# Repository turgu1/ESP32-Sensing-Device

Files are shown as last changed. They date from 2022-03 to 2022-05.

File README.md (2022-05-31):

# ESP32 Sensing device V2.0

## Updates

(Updated May 31, 2022)

Received the V2.0 PCBs yesterday. First modifications (Not shown on the schematic):

- Led resistors (R13, R16): 1 kOhms instead of 220 Ohms (the LEDs are way too bright).
- Thermistor 10 kOhms resistor R11 hooked to GPIO25 instead of 3.3V using a wire: To diminish thermistor heath effect on reading values, the GPIO25 is put high only at thermistor read time.

The thermistor is only used when the device is connected to an external source of power: to get an accurate 3.3v source for thermistor read-outs.

To compensate for the lack of linearity of the ESP32 A2D, a lookup table has been generated and used by the software (ESPHome). See the generator here: `software/lut_gener.ino` Pins 34 and 25 must be connected before using the generator (without the GPIO34 resistor). Must be used for each ESP32 instance (will be different for each ESP32 chip). An example of the generated table can be found here: `software/.freezer_adc_lut.h`.

An ESPHome example of use to sense a Freezer is supplied in `software/freezer.yaml`.

(Updated May 19, 2022)

The new version is ready for production. Here are the modifications from version 1.0:

- Sensors using GPIO 15 (Generic sensor), 25 (thermistor) and 27 (light sensor) migrated to GPIO 32, 34 and 35 respectively
- Added I2C interface
- Added program-controlled led
- All parts are aligned in the same direction onboard, to simplify hand soldering
- The board is 0.6mm larger

(Updated May 18, 2022)

The thermistor and photo-resistor sensors are working well. As they use GPIO 25 and 27 A2D capability (ADC2), the WiFi interface cannot be enabled at the same time the sensors are being read: the ADC2 electronics is shared with the onboard  WiFi capability. An updated version of the device is being prepared to use ADC1 GPIOs instead. (This has been corrected in version 2.0)

(Updated May 17, 2022)

All the trials are positive so far. For R1, instead of 10K, I'm using 2.7M ohms.
Remains the thermistor and photo-resistor sensors to try.

(Updated March 29, 2022)

Initial release.

## Introduction

This is a small footprint ESP32-based sensing device, with the following characteristics:

- 30x28 mm circuit board (30x40 mm with ESP32 antenna)
- Two power modes:
    - Battery (AAx2) (through external battery case)
    - External 5 Volts power support (through power-only Micro USB-B port)
- Battery level monitoring circuit
- Three Sensing ports:
    - Multi-Purpose (configurable through Resistor and Capacitor parts)
    - Thermistor (https://learn.adafruit.com/thermistor/using-a-thermistor)
    - Photoresistor (https://learn.adafruit.com/photocells/using-a-photocell)
- I2C Interface port
- External FTDI port (through a 3-pins [GND, RxD, TxD] port) (https://learn.adafruit.com/ftdi-friend)
- RST / PGM buttons
- Power LED (for external power only)
- Programmable LED
- Designed with KiCAD V6.0.5 (https://www.kicad.org)
- Public Domain

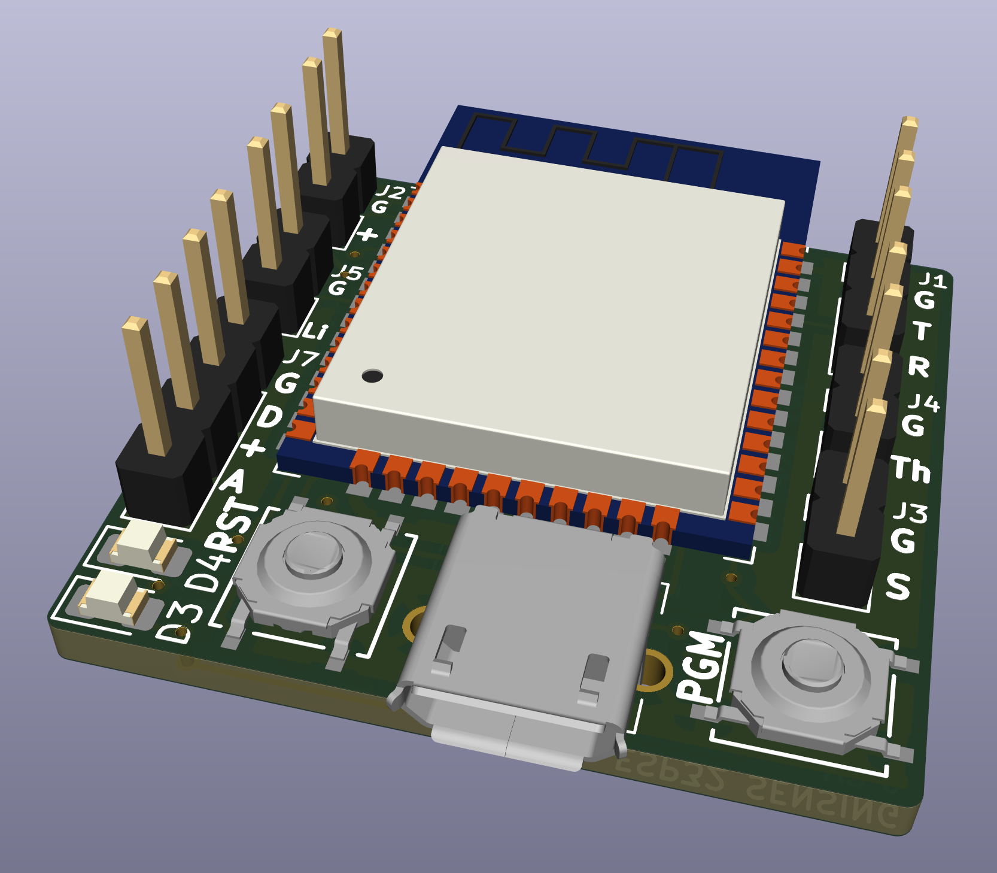
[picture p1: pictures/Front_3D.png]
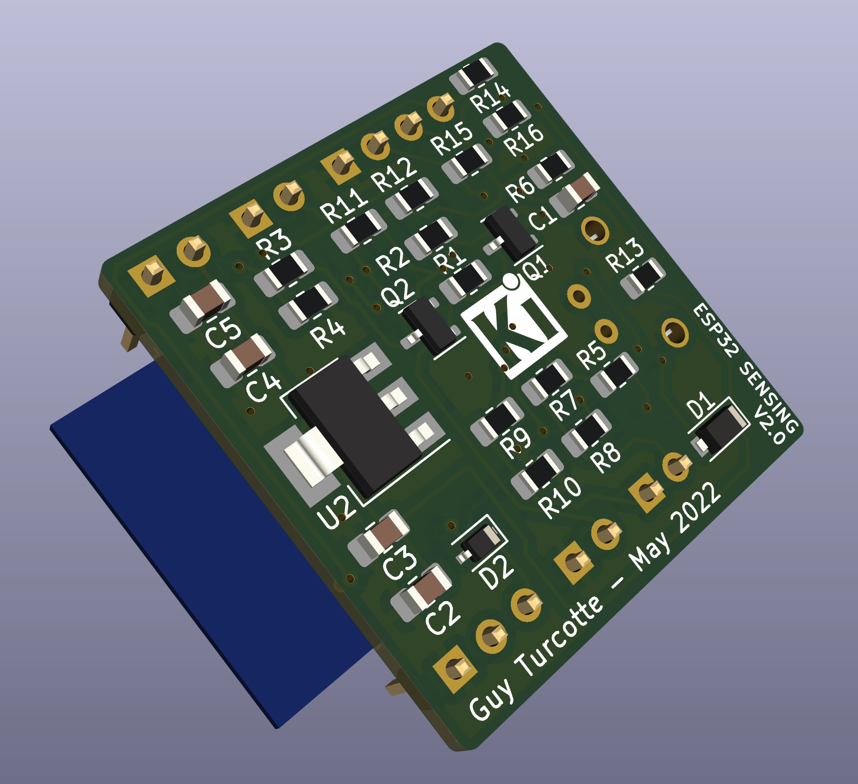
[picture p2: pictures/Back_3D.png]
&nbsp;&nbsp;&nbsp;&nbsp;

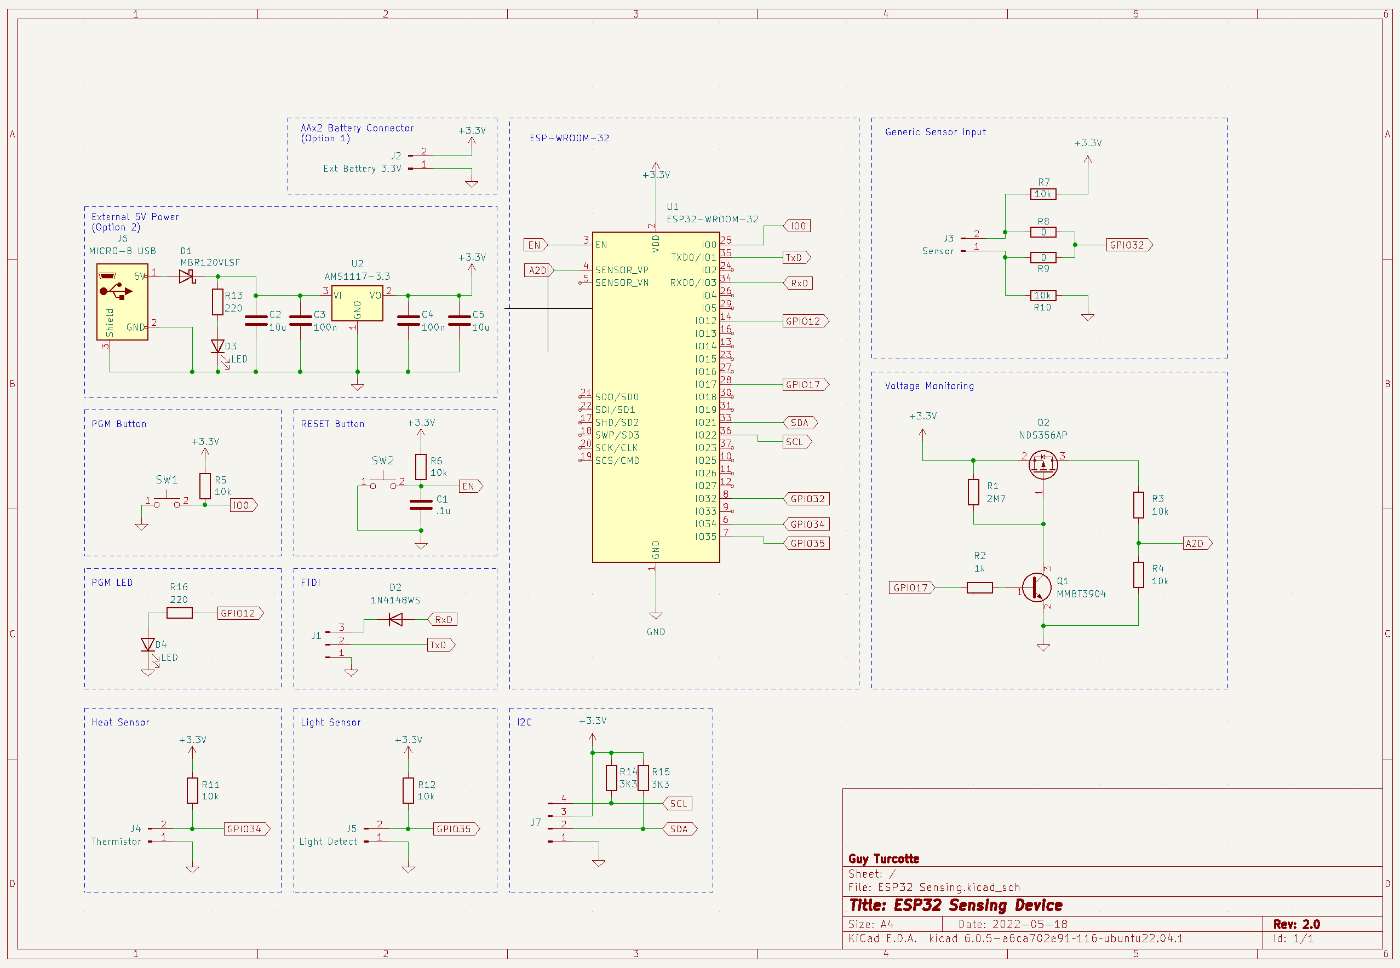
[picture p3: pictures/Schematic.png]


The choice of components is related to their availability in my inventory. 

## Design Description

Looking at the schematic, you will find here the information related to each subsection present on the device. Some subsections are required, and others are optional depending on your needs.

The electronic component identifiers required for each subsection are listed inside square brackets.

### Required Subsections

- **ESP-WROOM-32** [**U1**] - This is the processor in use on the device.
- **RESET Button** [**SW2**, **R6**, **C1**] - Required to maintain the processor working and do a reset when it is required to take back the control for programming or when the device is not behaving properly.
- **PGM Button** [**SW1**, **R5**] - For programming the processor, the PGM Button must be pressed as the reset button is also pressed, and then released *after* releasing the reset button, such that the processor will be put in program loading. The FTDI interface must be connected to the computer to transmit the new program.
- **FTDI** [**D2**, **J1**] - This is the connection to an external FTDI device that allows for communication between the ESP32 processor and a development PC for program loading and debugging output. Connector's pins are labeled **G** (Ground), **R** (RxD), and **T** (TxD) relative to the ESP32 pinout: The External FTDI GND pin must be connected to **G**, the FTDI RxD pin must be connected to **T**, and the FTDI TxD pin must be connected to **R**. Power must be supplied to the board through AA batteries or an external power supply.

### Optional Subsections

- **AAx2 Battery Connector** [**J2**] - If power is to be supplied with AA batteries, the connector is required. The battery holder wires can also be directly soldered in the through-holes. Please respect the polarity (a '+' sign is present on the board to indicate the positive wire location). **Do not connect any battery if you intend to use an external power supply.**
- **External 5V Power**, [**U2**, **J6**, **D1**, **D3**, **R13**, **C2**, **C3**, **C4**, **C5**] - This is a linear 3.3V regulator circuit, only required when a DC 5 Volts power supply is used. It is expected that the power supply is using a male micro USB-B connector. **Do not implement this subsection if you intend to use batteries.**
- **Voltage Monitoring** [**Q1**, **Q2**, **R1**, **R2**, **R3**, **R4**] - This circuit will allow for reading the 3.3 V power voltage for the device through ADC1_0 internal to the ESP32. If AA batteries are used, it will allow monitoring the battery level to replace them when required. The MOSFET transistor [**Q2**] insure that the circuit will not take a load on the batteries. Must be enabled through [**Q1**] using GPIO17.
- **Generic Sensor Input** [**J3**, **R7**, **R8**, **R9**, **R10**] - This is a port to retrieve some sensor information. The four resistors must be adjusted to consider the kind of sensing to be done (pull-up, pull-down, etc.). Some resistor locations can be used for capacitors if required (e.g. adding an RC circuit). This sensor is connected to GPIO32 (ADC1_4) of the ESP32. The J3 pins are labeled 1: G (Gnd), 2: S (Signal).
- **Heat Sensor** [**J4**, **R11**] - Allow for reading the level of Heat using an external thermistor through an A2D of the processor (ADC1). This sensor is connected to GPIO34 (ADC1_6) of the ESP32. Can be used with another kind of sensor as appropriate. The J4 pins are labeled 1: G (Gnd), 2: Th (Signal).
- **Light Sensor** [**J5**, **R12**] - Allow for reading the level of Heat using an external photoresistor through an A2D of the processor (ADC1). This sensor is connected to GPIO35 (ADC1_7) of the ESP32. Can be used with another kind of sensor as appropriate. The J5 pins are labeled 1: G (Gnd), 2: Li (Signal).
- **I2C Interface** [**J7**, **R14**, **R15**] - Used to connect to external I2C devices (displays, sensors, etc). Connected to the ESP32 through GPIO21 (SDA) and GPIO22 (SCL). The J7 connector offers 3.3v and GND pins. Resistors may have to be adjusted depending on the load. The J7 Pins are labeled 1: G (ground), 2: D (SDA), 3: + (3.3v), 4: C (SCL)
- **Program Controlled LED** [**D4**, **R16**] - Could be useful for debugging purpose. Not a good idea to use it on battery-powered devices. Connected to ESP32 GPIO12. Important: Must be programmed as an output GPIO.



### Some potential issues

- The thermistor and photoresistive interfaces are exploratory. The known lack of linearity of the ESP32 A2D may have an impact on the quality of the retrieved data. See [here](https://www.e-tinkers.com/2019/10/using-a-thermistor-with-arduino-and-unexpected-esp32-adc-non-linearity/), and [here](https://rntlab.com/question/analogread-for-ntc-thermistor/) for further information.

- The Micro USB-B connector is a specific part with only 2 through-hole pins (GND and 5V). See the BOM below for purchase locations. On Amazon, there are 100, 30, and 10 pieces bundles available. A more conventional 5-pins connector may be adapted (physical tweak or modification to the board design).

- The Power LED is for use only with the external power supply and is hooked on the 5v side of the linear regulator. It could have been hooked to the 3.3v side, closer to the ESP32.

- The linear 3.3v regulator capacitors may have to be different than the one selected. In particular, on the output side, to get a better transient response, a 22uF tantalum may replace the one indicated (per the AMS1117 spec sheet).

- Using batteries to power the device: depending on the processor speed and the networking requirements at startup (WiFi, BT, BLE), the AA batteries may not be able to supply the required startup current (100 to 500 mA). Many options are possible: use larger batteries, lithium instead of alkaline, and add some capacitors (tantalum or other) at C4/C5 locations.

## Bill of Material (BOM)

| Reference(s) | Value | Footprint | Where to find |
|:---:|:-----:|:---:|:---|
| C1 | .1uF  | 0805 | |
| C2, C5 | 10uF  | 0805 | |
| C3, C4 | 100nF | 0805 | |
| D1 | MBR120VLSF or equivalent | SOD-123 | [e-Radionica](https://e-radionica.com/en/schottky-diode-mbr120vlsft3g-sod123.html), [Digikey](https://www.digikey.com/en/products/detail/on-semiconductor/MBR120VLSFT3G/1477157), [Mouser](https://www.mouser.com/ProductDetail/onsemi/MBR120VLSFT3G?qs=3JMERSakebrD2yr9jFliaA%3D%3D) |
| D2 | 1N4148WS | SOD-323 | [Digikey](https://www.digikey.com/en/products/detail/on-semiconductor/1N4148WS/1873805), [Mouser](https://www.mouser.ca/ProductDetail/onsemi-Fairchild/1N4148WS?qs=2%2FYqgE%252BHg%252BKBrKZlAsMLhw%3D%3D) |
| D3, D4 | LED | 0805 | |
| J1 | Connector 1x3 | Pin Header 2.54mm | |
| J2, J3, J4, J5 | Connector 1x2 | Pin Header 2.54mm | |
| J6 | Micro-B USB | | [AliExpress](https://fr.aliexpress.com/item/32886396127.html?gatewayAdapt=glo2fra), [Amazon](https://www.amazon.com/uxcell-100PCS-Connector-Replacement-Adapter/dp/B07R1HG29D/ref=psdc_172544_t1_B07R1HRM1T) |
| J7 | Connector 1x4 | Pin Header 2.54mm | |
| Q1 | MMBT3904 | SOT-23 | |
| Q2 | NDS356AP or IRLML5103TRPBF or equivalent | SOT-23 | |
| R1, R3 to R7, R10 to R12 | 10k ohms | 0805 | |
| R2 | 1k ohms | 0805 | |
| R8, R9 | 0 ohms | 0805 | |
| R13, R16 | 220 ohms | 0805 | |
| R14, R15 | 3.3k ohms | 0805 | |
| SW1, SW2 | PTS526_SK15_SMTR2_LFS | SMTR2 | [Mouser](https://www.mouser.com/ProductDetail/CK/PTS526-SK15-SMTR2-LFS?qs=UXgszm6BlbF5Ezp94JAQtw%3D%3D), [Digikey](https://www.digikey.com/en/products/detail/c-k/PTS526-SK15-SMTR2-LFS/10056626), [e-Radionica](https://e-radionica.com/en/smd-pushbutton.html) |
| U1 | ESP-WROOM-32 | | [e-Radionica](https://e-radionica.com/en/esp32-wroom-32d-wifi-module.html) |
| U2 | AMS1117-3.3 | SOT-223-3 | |

## Copyright (c) 2022 Guy Turcotte

Permission is hereby granted, free of charge, to any person obtaining a copy of this project and associated documentation files (the "Project Content"), to deal in the Project without restriction, including without limitation the rights to use, copy, modify, merge, publish, distribute, sublicense, and/or sell copies of the Project Content, and to permit persons to whom the Project Content is furnished to do so, subject to the following conditions:

The above copyright notice and this permission notice shall be included in all copies or substantial portions of the Project Content.

THE PROJECT CONTENT IS PROVIDED "AS IS", WITHOUT WARRANTY OF ANY KIND, EXPRESS OR IMPLIED, INCLUDING BUT NOT LIMITED TO THE WARRANTIES OF MERCHANTABILITY, FITNESS FOR A PARTICULAR PURPOSE, AND NON-INFRINGEMENT. IN NO EVENT SHALL THE AUTHORS OR COPYRIGHT HOLDERS BE LIABLE FOR ANY CLAIM, DAMAGES, OR OTHER LIABILITY, WHETHER IN AN ACTION OF CONTRACT, TORT OR OTHERWISE, ARISING FROM, OUT OF OR IN CONNECTION WITH THE PROJECT CONTENT OR THE USE OR OTHER DEALINGS IN THE PROJECT CONTENT.

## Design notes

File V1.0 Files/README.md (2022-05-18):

# ESP32 Sensing device V1.0

(Update May 18, 2022)

The thermistor and photo-resistor sensors are working well. As they use GPIO 25 and 27 A2D capability (ADC2), the WiFi interface cannot be enabled at the same time the sensors are being read: the ADC2 electronics is shared with the onboard  WiFi capability. An updated version of the device is being prepared to use ADC1 GPIOs instead.

(Update May 17, 2022)

All the trials are positive so far. For R1, instead of 10K, I'm using 2.7M ohms.
Remains the thermistor and photo-resistor sensors to try.

(Updated March 29, 2022)

This is a small footprint ESP32-based sensing device, with the following characteristics:

- 30x28 mm circuit board (30x40 mm with ESP32 antenna)
- Two power modes:
    - Battery (AAx2) (through external battery case)
    - External 5 Volts power support (through power-only Micro USB-B port)
- Battery level monitoring circuit
- Three Sensing ports:
    - Multi-Purpose (configurable through Resistor and Capacitor parts)
    - Thermistor (https://learn.adafruit.com/thermistor/using-a-thermistor)
    - Photoresistor (https://learn.adafruit.com/photocells/using-a-photocell)
- External FTDI port (through a 3-pins [GND, RxD, TxD] port) (https://learn.adafruit.com/ftdi-friend)
- RST / PGM buttons
- Power LED (for external power only)
- Designed with KiCAD V6.0.4 (https://www.kicad.org)
- Public Domain

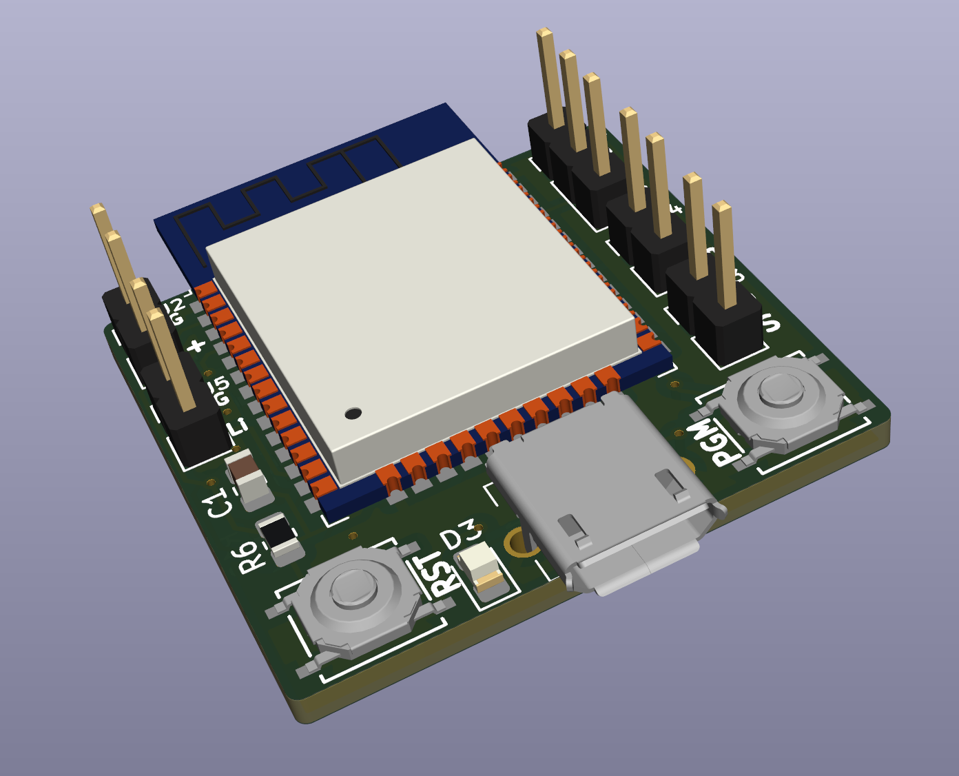
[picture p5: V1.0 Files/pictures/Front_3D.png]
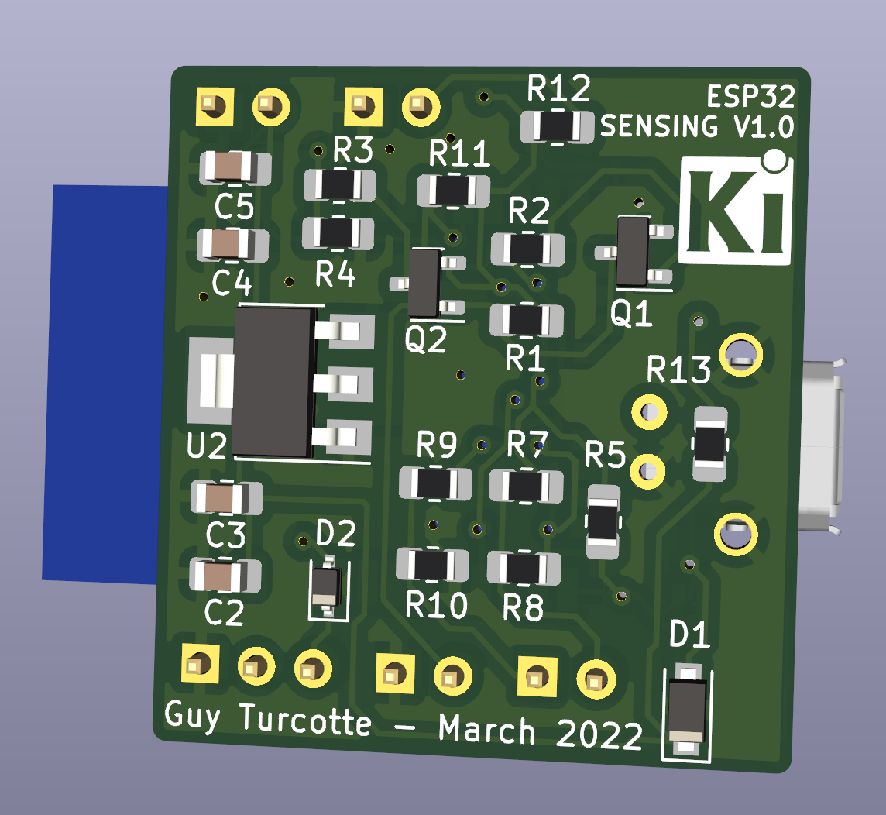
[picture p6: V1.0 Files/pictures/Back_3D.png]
&nbsp;&nbsp;&nbsp;&nbsp;

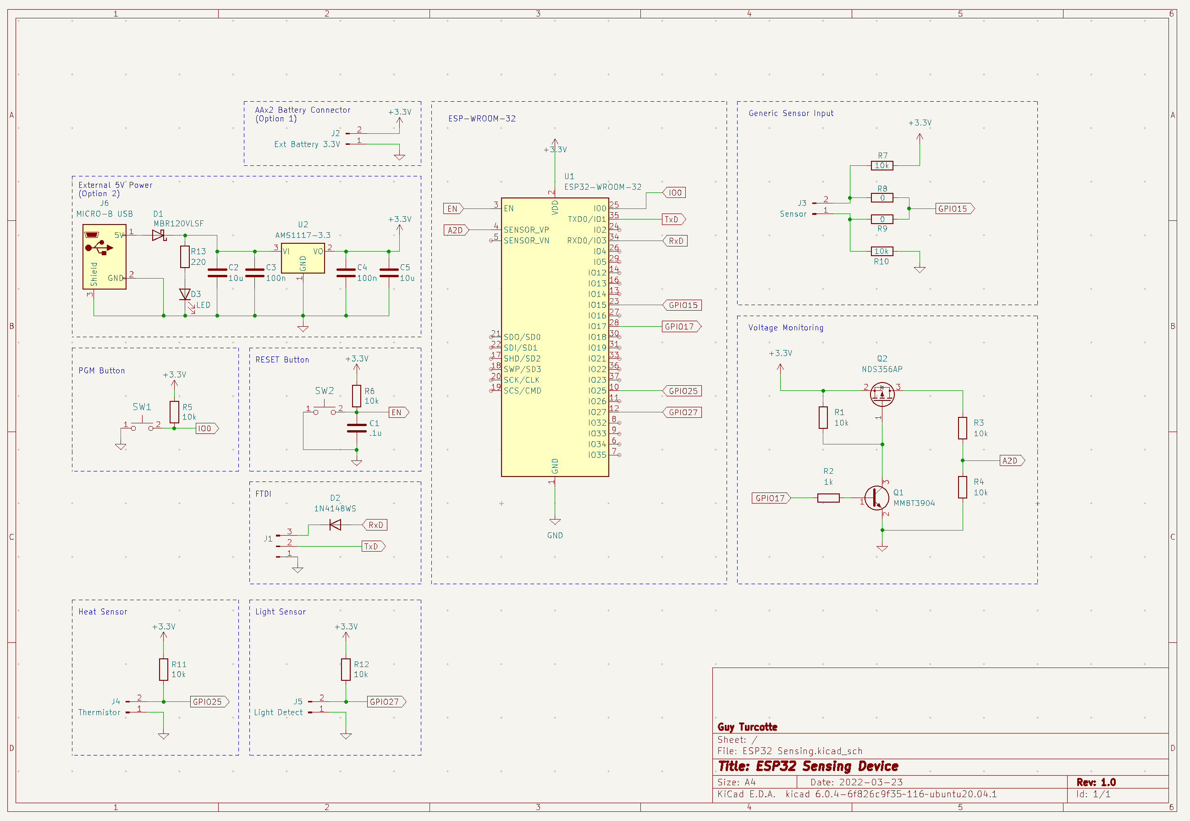
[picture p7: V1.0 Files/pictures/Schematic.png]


The choice of components is related to their availability in my inventory. 

## Design Description

Looking at the schematic, you will find here the information related to each subsection present on the device. Some subsections are required, others are optional depending on your needs.

The electronic component identifiers required for each subsection are listed inside square brackets.

### Required Subsections

- **ESP-WROOM-32** [**U1**] - This is the processor in use on the device.
- **RESET Button** [**SW2**, **R6**, **C1**] - Required to maintain the processor working and do a reset when it is required to take back the control for programming or when the device is not behaving properly.
- **PGM Button** [**SW1**, **R5**] - For programming the processor, the PGM Button must be pressed as the reset button is also pressed such that the processor will be put in program loading. The FTDI interface must be connected to the computer to transmit the new program.
- **FTDI** [**D2**, **J1**] - This is the connection to an external FTDI device that allows for communication between the ESP32 processor and a development PC for program loading and debugging output. Connector's pins are labeled **G** (Ground), **R** (RxD), and **T** (TxD) relative to the ESP32 pinout: The External FTDI GND pin must be connected to **G**, the FTDI RxD pin must be connected to **T**, and the FTDI TxD pin must be connected to **R**. Power must be supplied to the board through AA batteries or external power supply.

### Optional Subsections

- **AAx2 Battery Connector** [**J2**] - If power is to be supplied with AA batteries, the connector is required. The batteries holder wires can also be directly soldered in the through-holes. Please respect the polarity (a '+' sign is present on the board to indicate the positive wire location). **Do not connect any battery if you intend to use an external power supply.**
- **External 5V Power**, [**U2**, **J6**, **D1**, **D3**, **R13**, **C2**, **C3**, **C4**, **C5**] - This is a linear 3.3V regulator circuit, only required when a DC 5 Volts power supply is used. It is expected that the power supply is using a male micro USB-B connector. **Do not implement this subsection if you intend to use batteries.**
- **Voltage Monitoring** [**Q1**, **Q2**, **R1**, **R2**, **R3**, **R4**] - This circuit will allow for reading the 3.3 V power voltage for the device through ADC1_0 internal to the ESP32. If AA batteries are used, it will allow monitoring the battery level to replace them when required. The MOSFET transistor [**Q2**] insure that the circuit will not take a load on the batteries. Must be enabled through [**Q1**] using GPIO17.
- **Generic Sensor Input** [**J3**, **R7**, **R8**, **R9**, **R10**] - This is a port to retrieve some sensor information. The four resistors must be adjusted to consider the kind of sensing to be done (pull-up, pull-down, etc.). Some resistors locations can be used for capacitors if required (e.g. adding an RC circuit). This sensor is connected to GPIO15 (ADC2_3) of the ESP32.
- **Heat Sensor** [**J4**, **R11**] - Allow for reading the level of Heat using an external thermistor through an A2D of the processor (ADC2). This sensor is connected to GPIO25 (ADC2_8) of the ESP32. Can be used with another kind of sensor as appropriate. As the ADC2 circuitry is also used by the WiFi interface, the WiFi interface cannot be enabled at the same time the sensor is being read.
- **Light Sensor** [**J5**, **R12**] - Allow for reading the level of Heat using an external photoresistor through an A2D of the processor (ADC2). This sensor is connected to GPIO27 (ADC2_7) of the ESP32. Can be used with another kind of sensor as appropriate. As the ADC2 circuitry is also used by the WiFi interface, the WiFi interface cannot be enabled at the same time the sensor is being read.



### Some potential issues

- The thermistor and photoresistive interfaces are exploratory. The known lack of linearity of the ESP32 A2D may have an impact on the quality of the retrieved data. See [here](https://www.e-tinkers.com/2019/10/using-a-thermistor-with-arduino-and-unexpected-esp32-adc-non-linearity/), and [here](https://rntlab.com/question/analogread-for-ntc-thermistor/) for further information.

- The Micro USB-B connector is a specific part with only 2 through-hole pins (GND and 5V). See the BOM below for purchase locations. On Amazon, there are 100, 30, and 10 pieces bundles available. A more conventional 5-pins connector may be adapted (physical tweak or modification to the board design).

- The LED is for use only with the external power supply and is hooked on the 5v side of the linear regulator. It could have been hooked to the 3.3v side, closer to the ESP32.

- The linear 3.3v regulator capacitors may have to be different than the one selected. In particular, on the output side, to get a better transient response, a 22uF tantalum may replace the one indicated (per the AMS1117 spec sheet).

- Using batteries to power the device: depending on the processor speed and the networking requirements at startup (WiFi, BT, BLE), the AA batteries may not be able to supply the required startup current (100 to 500 mA). Many options are possible: use larger batteries, lithium instead of alkaline, add some capacitors (tantalum or other) at C4/C5 locations.

## Bill of Material (BOM)

| Reference(s) | Value | Footprint | Where to find |
|:---:|:-----:|:---:|:---|
| C1 | .1uF  | 0805 | |
| C2, C5 | 10uF  | 0805 | |
| C3, C4 | 100nF | 0805 | |
| D1 | MBR120VLSF or equivalent | SOD-123 | [e-Radionica](https://e-radionica.com/en/schottky-diode-mbr120vlsft3g-sod123.html), [Digikey](https://www.digikey.com/en/products/detail/on-semiconductor/MBR120VLSFT3G/1477157), [Mouser](https://www.mouser.com/ProductDetail/onsemi/MBR120VLSFT3G?qs=3JMERSakebrD2yr9jFliaA%3D%3D) |
| D2 | 1N4148WS | SOD-323 | [Digikey](https://www.digikey.com/en/products/detail/on-semiconductor/1N4148WS/1873805), [Mouser](https://www.mouser.ca/ProductDetail/onsemi-Fairchild/1N4148WS?qs=2%2FYqgE%252BHg%252BKBrKZlAsMLhw%3D%3D) |
| D3 | LED | 0805 | |
| J1 | Connector 1x3 | Pin Header 2.54mm | |
| J2, J3, J4, J5 | Connector 1x2 | Pin Header 2.54mm | |
| J6 | Micro-B USB | | [AliExpress](https://fr.aliexpress.com/item/32886396127.html?gatewayAdapt=glo2fra), [Amazon](https://www.amazon.com/uxcell-100PCS-Connector-Replacement-Adapter/dp/B07R1HG29D/ref=psdc_172544_t1_B07R1HRM1T) |
| Q1 | MMBT3904 | SOT-23 | |
| Q2 | NDS356AP or IRLML5103TRPBF or equivalent | SOT-23 | |
| R1, R3 to R7, R10 to R12 | 10k ohms | 0805 | |
| R2 | 1k ohms | 0805 | |
| R8, R9 | 0 ohms | 0805 | |
| R13 | 220 ohms | 0805 | |
| SW1, SW2 | PTS526_SK15_SMTR2_LFS | SMTR2 | [Mouser](https://www.mouser.com/ProductDetail/CK/PTS526-SK15-SMTR2-LFS?qs=UXgszm6BlbF5Ezp94JAQtw%3D%3D), [Digikey](https://www.digikey.com/en/products/detail/c-k/PTS526-SK15-SMTR2-LFS/10056626), [e-Radionica](https://e-radionica.com/en/smd-pushbutton.html) |
| U1 | ESP-WROOM-32 | | [e-Radionica](https://e-radionica.com/en/esp32-wroom-32d-wifi-module.html) |
| U2 | AMS1117-3.3 | SOT-223-3 | |

## Copyright (c) 2022 Guy Turcotte

Permission is hereby granted, free of charge, to any person obtaining a copy of this project and associated documentation files (the "Project Content"), to deal in the Project without restriction, including without limitation the rights to use, copy, modify, merge, publish, distribute, sublicense, and/or sell copies of the Project Content, and to permit persons to whom the Project Content is furnished to do so, subject to the following conditions:

The above copyright notice and this permission notice shall be included in all copies or substantial portions of the Project Content.

THE PROJECT CONTENT IS PROVIDED "AS IS", WITHOUT WARRANTY OF ANY KIND, EXPRESS OR IMPLIED, INCLUDING BUT NOT LIMITED TO THE WARRANTIES OF MERCHANTABILITY, FITNESS FOR A PARTICULAR PURPOSE, AND NON-INFRINGEMENT. IN NO EVENT SHALL THE AUTHORS OR COPYRIGHT HOLDERS BE LIABLE FOR ANY CLAIM, DAMAGES, OR OTHER LIABILITY, WHETHER IN AN ACTION OF CONTRACT, TORT OR OTHERWISE, ARISING FROM, OUT OF OR IN CONNECTION WITH THE PROJECT CONTENT OR THE USE OR OTHER DEALINGS IN THE PROJECT CONTENT.

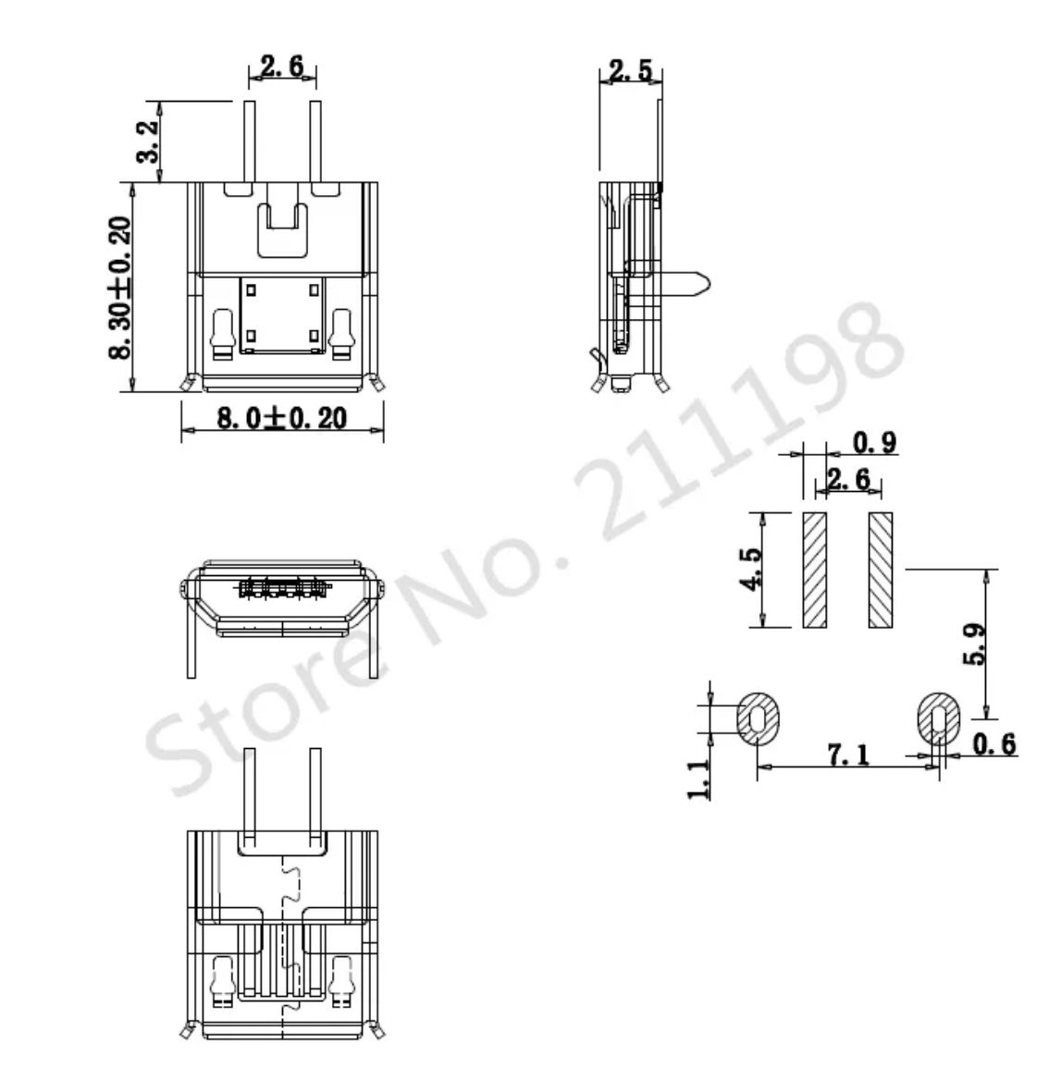
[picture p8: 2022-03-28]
V1.0 Files/pictures/Micro USB-B 2-pins dimensions.png

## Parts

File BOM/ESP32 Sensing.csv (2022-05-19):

Id | Designator | Package | Quantity | Designation | Supplier and ref
1 | J5 | PinHeader_1x02_P2.54mm_Vertical | 1 | Light Detect
2 | J3 | PinHeader_1x02_P2.54mm_Vertical | 1 | Sensor
3 | J7 | PinHeader_1x04_P2.54mm_Vertical | 1 | Conn_01x04_Male
4 | D4,D3 | LED_0805_2012Metric_Pad1.15x1.40mm_HandSolder | 2 | LED
5 | SW1 | PTS526_SK15_SMTR2_LFS | 1 | PTS526_SK15_SMTR2_LFS
6 | J1 | PinHeader_1x03_P2.54mm_Vertical | 1 | ~
7 | J2 | PinHeader_1x02_P2.54mm_Vertical | 1 | Ext Battery 3.3V
8 | U1 | ESP32-WROOM-32 | 1 | ESP32-WROOM-32
9 | J4 | PinHeader_1x02_P2.54mm_Vertical | 1 | Thermistor
10 | SW2 | PTS526_SK15_SMTR2_LFS | 1 | ~
11 | J6 | MICRO-B_USB_POWER | 1 | MICRO-B USB
12 | R13,R16 | R_0805_2012Metric_Pad1.20x1.40mm_HandSolder | 2 | 220
13 | R7,R4,R3,R10,R5,R12,R6,R11 | R_0805_2012Metric_Pad1.20x1.40mm_HandSolder | 8 | 10k
14 | R15,R14 | R_0805_2012Metric_Pad1.20x1.40mm_HandSolder | 2 | 3K3
15 | C4,C3 | C_0805_2012Metric_Pad1.18x1.45mm_HandSolder | 2 | 100n
16 | Q1 | SOT-23 | 1 | MMBT3904
17 | R9,R8 | R_0805_2012Metric_Pad1.20x1.40mm_HandSolder | 2 | 0
18 | D1 | D_SOD-123F | 1 | MBR120VLSF
19 | R2 | R_0805_2012Metric_Pad1.20x1.40mm_HandSolder | 1 | 1k
20 | D2 | D_SOD-323 | 1 | 1N4148WS
21 | R1 | R_0805_2012Metric_Pad1.20x1.40mm_HandSolder | 1 | 2M7
22 | U2 | SOT-223-3_TabPin2 | 1 | AMS1117-3.3
23 | C2,C5 | C_0805_2012Metric_Pad1.18x1.45mm_HandSolder | 2 | 10u
24 | Q2 | SOT-23 | 1 | NDS356AP
25 | C1 | C_0805_2012Metric_Pad1.18x1.45mm_HandSolder | 1 | .1u

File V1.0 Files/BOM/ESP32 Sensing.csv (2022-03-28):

Source: | /home/turgu1/Dev/KiCad/ESP32 Sensing/KiCAD/ESP32 Sensing.kicad_sch
Date: | Mon 28 Mar 2022 03:08:43 PM
Tool: | Eeschema 6.0.4-6f826c9f35~116~ubuntu20.04.1
Generator: | /usr/share/kicad/plugins/bom_csv_grouped_by_value.py
Component Count: | 33
Individual Components:
Item | Qty | Reference(s) | Value | LibPart | Footprint | Datasheet
 |  | C1 | .1u | Device:C | Capacitor_SMD:C_0805_2012Metric_Pad1.18x1.45mm_HandSolder | ~
 |  | C2 | 10u | Device:C | Capacitor_SMD:C_0805_2012Metric_Pad1.18x1.45mm_HandSolder | ~
 |  | C3 | 100n | Device:C | Capacitor_SMD:C_0805_2012Metric_Pad1.18x1.45mm_HandSolder | ~
 |  | C4 | 100n | Device:C | Capacitor_SMD:C_0805_2012Metric_Pad1.18x1.45mm_HandSolder | ~
 |  | C5 | 10u | Device:C | Capacitor_SMD:C_0805_2012Metric_Pad1.18x1.45mm_HandSolder | ~
 |  | D1 | MBR120VLSF | Diode:MBR1020VL | Diode_SMD:D_SOD-123F | https://www.onsemi.com/pub/Collateral/MBR1020VL-D.PDF
 |  | D2 | 1N4148WS | Diode:1N4148WS | Diode_SMD:D_SOD-323 | https://www.vishay.com/docs/85751/1n4148ws.pdf
 |  | D3 | LED | Device:LED | LED_SMD:LED_0805_2012Metric_Pad1.15x1.40mm_HandSolder | ~
 |  | J1 | ~ | Connector:Conn_01x03_Male | Connector_PinHeader_2.54mm:PinHeader_1x03_P2.54mm_Vertical | ~
 |  | J2 | Ext Battery 3.3V | Connector:Conn_01x02_Male | Connector_PinHeader_2.54mm:PinHeader_1x02_P2.54mm_Vertical | ~
 |  | J3 | Sensor | Connector:Conn_01x02_Male | Connector_PinHeader_2.54mm:PinHeader_1x02_P2.54mm_Vertical | ~
 |  | J4 | Thermistor | Connector:Conn_01x02_Male | Connector_PinHeader_2.54mm:PinHeader_1x02_P2.54mm_Vertical | ~
 |  | J5 | Light Detect | Connector:Conn_01x02_Male | Connector_PinHeader_2.54mm:PinHeader_1x02_P2.54mm_Vertical | ~
 |  | J6 | MICRO-B USB | ESP32 Sensing:MICRO-B_USB_POWER | ESP32 Sensing:MICRO-B_USB_POWER
 |  | Q1 | MMBT3904 | Transistor_BJT:MMBT3904 | Package_TO_SOT_SMD:SOT-23 | https://www.onsemi.com/pub/Collateral/2N3903-D.PDF
 |  | Q2 | NDS356AP | ESP32 Sensing:NDS356AP | Package_TO_SOT_SMD:SOT-23 | https://rocelec.widen.net/view/pdf/qv8gjztlsc/ONSM-S-A0003585169-1.pdf?t.download=true&u=5oefqw
 |  | R1 | 10k | Device:R | Resistor_SMD:R_0805_2012Metric_Pad1.20x1.40mm_HandSolder | ~
 |  | R2 | 1k | Device:R | Resistor_SMD:R_0805_2012Metric_Pad1.20x1.40mm_HandSolder | ~
 |  | R3 | 10k | Device:R | Resistor_SMD:R_0805_2012Metric_Pad1.20x1.40mm_HandSolder | ~
 |  | R4 | 10k | Device:R | Resistor_SMD:R_0805_2012Metric_Pad1.20x1.40mm_HandSolder | ~
 |  | R5 | 10k | Device:R | Resistor_SMD:R_0805_2012Metric_Pad1.20x1.40mm_HandSolder | ~
 |  | R6 | 10k | Device:R | Resistor_SMD:R_0805_2012Metric_Pad1.20x1.40mm_HandSolder | ~
 |  | R7 | 10k | Device:R | Resistor_SMD:R_0805_2012Metric_Pad1.20x1.40mm_HandSolder | ~
 |  | R8 | 0 | Device:R | Resistor_SMD:R_0805_2012Metric_Pad1.20x1.40mm_HandSolder | ~
 |  | R9 | 0 | Device:R | Resistor_SMD:R_0805_2012Metric_Pad1.20x1.40mm_HandSolder | ~
 |  | R10 | 10k | Device:R | Resistor_SMD:R_0805_2012Metric_Pad1.20x1.40mm_HandSolder | ~
 |  | R11 | 10k | Device:R | Resistor_SMD:R_0805_2012Metric_Pad1.20x1.40mm_HandSolder | ~
 |  | R12 | 10k | Device:R | Resistor_SMD:R_0805_2012Metric_Pad1.20x1.40mm_HandSolder | ~
 |  | R13 | 220 | Device:R | Resistor_SMD:R_0805_2012Metric_Pad1.20x1.40mm_HandSolder | ~
 |  | SW1 | PTS526_SK15_SMTR2_LFS | ESP32 Sensing:PTS526_SK15_SMTR2_LFS | ESP32 Sensing:PTS526_SK15_SMTR2_LFS
 |  | SW2 | ~ | ESP32 Sensing:PTS526_SK15_SMTR2_LFS | ESP32 Sensing:PTS526_SK15_SMTR2_LFS
 |  | U1 | ESP32-WROOM-32 | RF_Module:ESP32-WROOM-32 | RF_Module:ESP32-WROOM-32 | https://www.espressif.com/sites/default/files/documentation/esp32-wroom-32_datasheet_en.pdf
 |  | U2 | AMS1117-3.3 | Regulator_Linear:AMS1117-3.3 | Package_TO_SOT_SMD:SOT-223-3_TabPin2 | http://www.advanced-monolithic.com/pdf/ds1117.pdf
Collated Components:
Item | Qty | Reference(s) | Value | LibPart | Footprint | Datasheet
1 | 1 | C1 | .1u | Device:C | Capacitor_SMD:C_0805_2012Metric_Pad1.18x1.45mm_HandSolder | ~
2 | 2 | C2, C5 | 10u | Device:C | Capacitor_SMD:C_0805_2012Metric_Pad1.18x1.45mm_HandSolder | ~
3 | 2 | C3, C4 | 100n | Device:C | Capacitor_SMD:C_0805_2012Metric_Pad1.18x1.45mm_HandSolder | ~
4 | 1 | D1 | MBR120VLSF | Diode:MBR1020VL | Diode_SMD:D_SOD-123F | https://www.onsemi.com/pub/Collateral/MBR1020VL-D.PDF
5 | 1 | D2 | 1N4148WS | Diode:1N4148WS | Diode_SMD:D_SOD-323 | https://www.vishay.com/docs/85751/1n4148ws.pdf
6 | 1 | D3 | LED | Device:LED | LED_SMD:LED_0805_2012Metric_Pad1.15x1.40mm_HandSolder | ~
7 | 1 | J1 | ~ | Connector:Conn_01x03_Male | Connector_PinHeader_2.54mm:PinHeader_1x03_P2.54mm_Vertical | ~
8 | 1 | J2 | Ext Battery 3.3V | Connector:Conn_01x02_Male | Connector_PinHeader_2.54mm:PinHeader_1x02_P2.54mm_Vertical | ~
9 | 1 | J3 | Sensor | Connector:Conn_01x02_Male | Connector_PinHeader_2.54mm:PinHeader_1x02_P2.54mm_Vertical | ~
10 | 1 | J4 | Thermistor | Connector:Conn_01x02_Male | Connector_PinHeader_2.54mm:PinHeader_1x02_P2.54mm_Vertical | ~
11 | 1 | J5 | Light Detect | Connector:Conn_01x02_Male | Connector_PinHeader_2.54mm:PinHeader_1x02_P2.54mm_Vertical | ~
12 | 1 | J6 | MICRO-B USB | ESP32 Sensing:MICRO-B_USB_POWER | ESP32 Sensing:MICRO-B_USB_POWER
13 | 1 | Q1 | MMBT3904 | Transistor_BJT:MMBT3904 | Package_TO_SOT_SMD:SOT-23 | https://www.onsemi.com/pub/Collateral/2N3903-D.PDF
14 | 1 | Q2 | NDS356AP | ESP32 Sensing:NDS356AP | Package_TO_SOT_SMD:SOT-23 | https://rocelec.widen.net/view/pdf/qv8gjztlsc/ONSM-S-A0003585169-1.pdf?t.download=true&u=5oefqw
15 | 9 | R1, R3, R4, R5, R6, R7, R10, R11, R12 | 10k | Device:R | Resistor_SMD:R_0805_2012Metric_Pad1.20x1.40mm_HandSolder | ~
16 | 1 | R2 | 1k | Device:R | Resistor_SMD:R_0805_2012Metric_Pad1.20x1.40mm_HandSolder | ~
17 | 2 | R8, R9 | 0 | Device:R | Resistor_SMD:R_0805_2012Metric_Pad1.20x1.40mm_HandSolder | ~
18 | 1 | R13 | 220 | Device:R | Resistor_SMD:R_0805_2012Metric_Pad1.20x1.40mm_HandSolder | ~
19 | 1 | SW1 | PTS526_SK15_SMTR2_LFS | ESP32 Sensing:PTS526_SK15_SMTR2_LFS | ESP32 Sensing:PTS526_SK15_SMTR2_LFS
20 | 1 | SW2 | ~ | ESP32 Sensing:PTS526_SK15_SMTR2_LFS | ESP32 Sensing:PTS526_SK15_SMTR2_LFS
21 | 1 | U1 | ESP32-WROOM-32 | RF_Module:ESP32-WROOM-32 | RF_Module:ESP32-WROOM-32 | https://www.espressif.com/sites/default/files/documentation/esp32-wroom-32_datasheet_en.pdf
22 | 1 | U2 | AMS1117-3.3 | Regulator_Linear:AMS1117-3.3 | Package_TO_SOT_SMD:SOT-223-3_TabPin2 | http://www.advanced-monolithic.com/pdf/ds1117.pdf

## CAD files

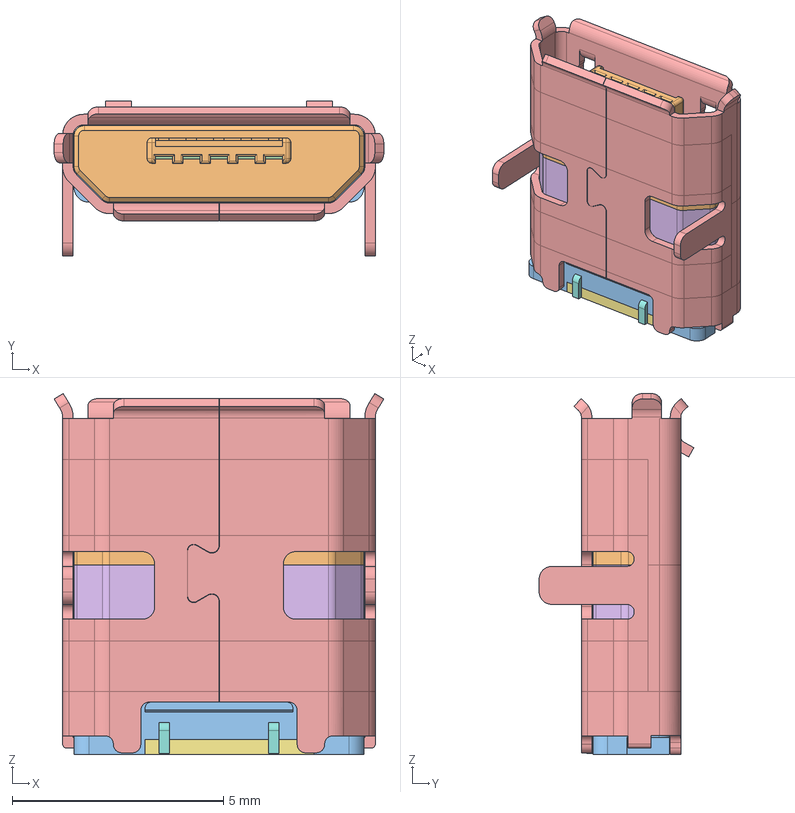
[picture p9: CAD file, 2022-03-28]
V1.0 Files/KiCAD/Parts/3D/Test2.stp
7.80 x 3.66 x 8.54 mm
Slice.8
Slice.9
Slice.10
Slice.11
Slice.12
Slice.13
Slice.7
Slice.6
Slice.2

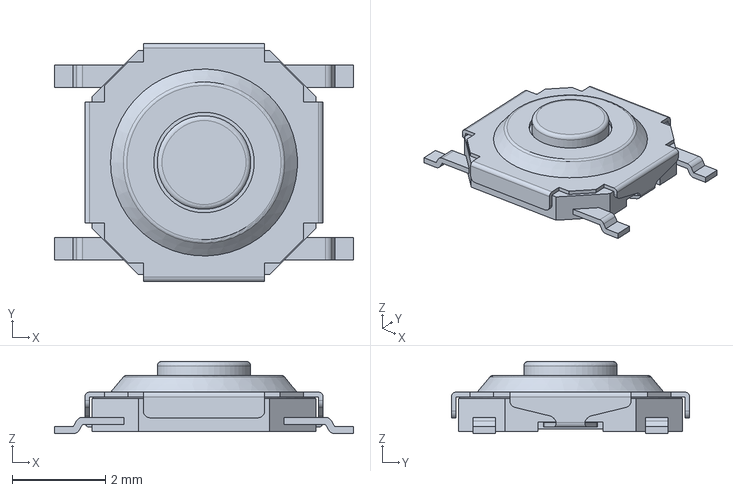
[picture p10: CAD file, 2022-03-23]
V1.0 Files/KiCAD/Parts/3D/PTS526_SK15_SMTR2_LFS.stp
6.40 x 5.10 x 1.55 mm

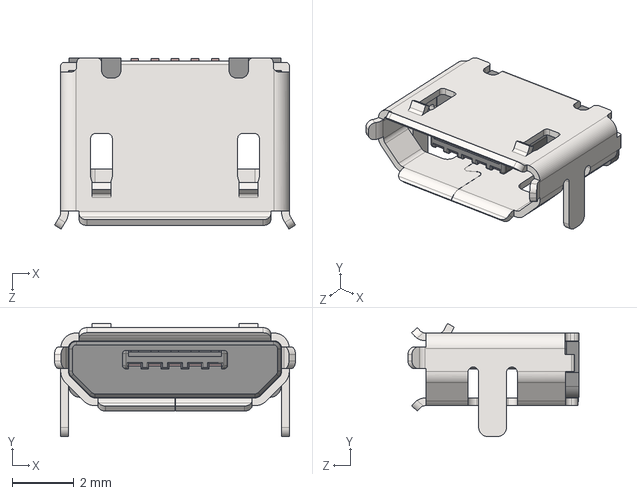
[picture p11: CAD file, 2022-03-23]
V1.0 Files/KiCAD/Parts/3D/USB3075-30-A.stp
7.80 x 3.66 x 5.54 mm

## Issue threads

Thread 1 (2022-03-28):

Ordering Boards

ModestMC, 2022-03-28:
Hey Guy,

I was just looking at some old WROOMs I have left over from my senior design project and thinking I should finally fix the PCB and order a new one. Instead, I decided to try finally playing with the Inkplate I got for Christmas. I decided to look at your repos and was both surprised and very happy to find this one!

I'm making this issue because ordinarily, you wind up having to order PCBs in sets of three or five. However, in my experience you're unlikely to use them all, especially when prototyping things(JLPCB winds up charging more for the shipping than the board). If you're interested, I'd be happy to buy one of the PCBs from you.

Cheers,
Mitchell

turgu1, 2022-03-28:
Hello Mitchell,
I'm waiting to get the boards. They have been prepared by PCBWay last week and I expect to get them in a week or two (transport through DHL from China). Where are you located?

ModestMC, 2022-03-29:
Nebraska! Should be the same continent I believe. Also, what are you hoping to do with the board once you have them?

turgu1, 2022-03-29:
I'm afraid I cannot send one to you. I have 10 of these boards that are coming. Two will be used for prototyping, the others will be installed in my house for sensing (water leak, smokes detectors, mailbox, mesh net). If I had one to spare with you, I would have to charge at least 20$ to send it to you (One hour of my time to prepare and go to the Post Office, complete a customs form, the cost of the car ride to go there, the cost of the PCB).

When you consider the price paid for 10 boards, It's about 3$ per board (etching cost: 5$, transportation: $23). This is not that expansive. Even if you need only one PCB, it's still a bargain. Here in Quebec City, a local etching company requests at least 100$ to produce a single board.

Digikey offers a service in California that wouldn't cost more than ordering from China I believe (at least for US people) for such a small PCB (31mm x 28 mm) when you add the cost of production and transportation (they call their low price etching DK RED). But you would not get the same quality of service from a shop like PCBWay (they do a lot of verification on the PCBs before shipping).

turgu1, 2022-03-29:
Here is the price at Digikey for 10 boards:
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

ModestMC, 2022-03-30:
No worries, I completely understand. I assumed this was a prototype board, but I should have realized someone as experienced as you probably knows exactly what the board they're looking for should do.

In that case, I will probably just fork your board, make some minor tweaks (mostly access to a few more pins) then put in an order myself. I already have to order stuff for the university so it should be simple enough to tack mine onto their shipping.

Thanks for getting back to me! Is there a good way I can drop you a line if I have questions about design elements of the board?

turgu1, 2022-03-30:
You are welcome. As I will mount and test the first PCB, I will add some info on my discoveries in the documentation. So stay tuned

Also, you may look at the potential issues I raised in the documentation...

Cheers!!
Guy

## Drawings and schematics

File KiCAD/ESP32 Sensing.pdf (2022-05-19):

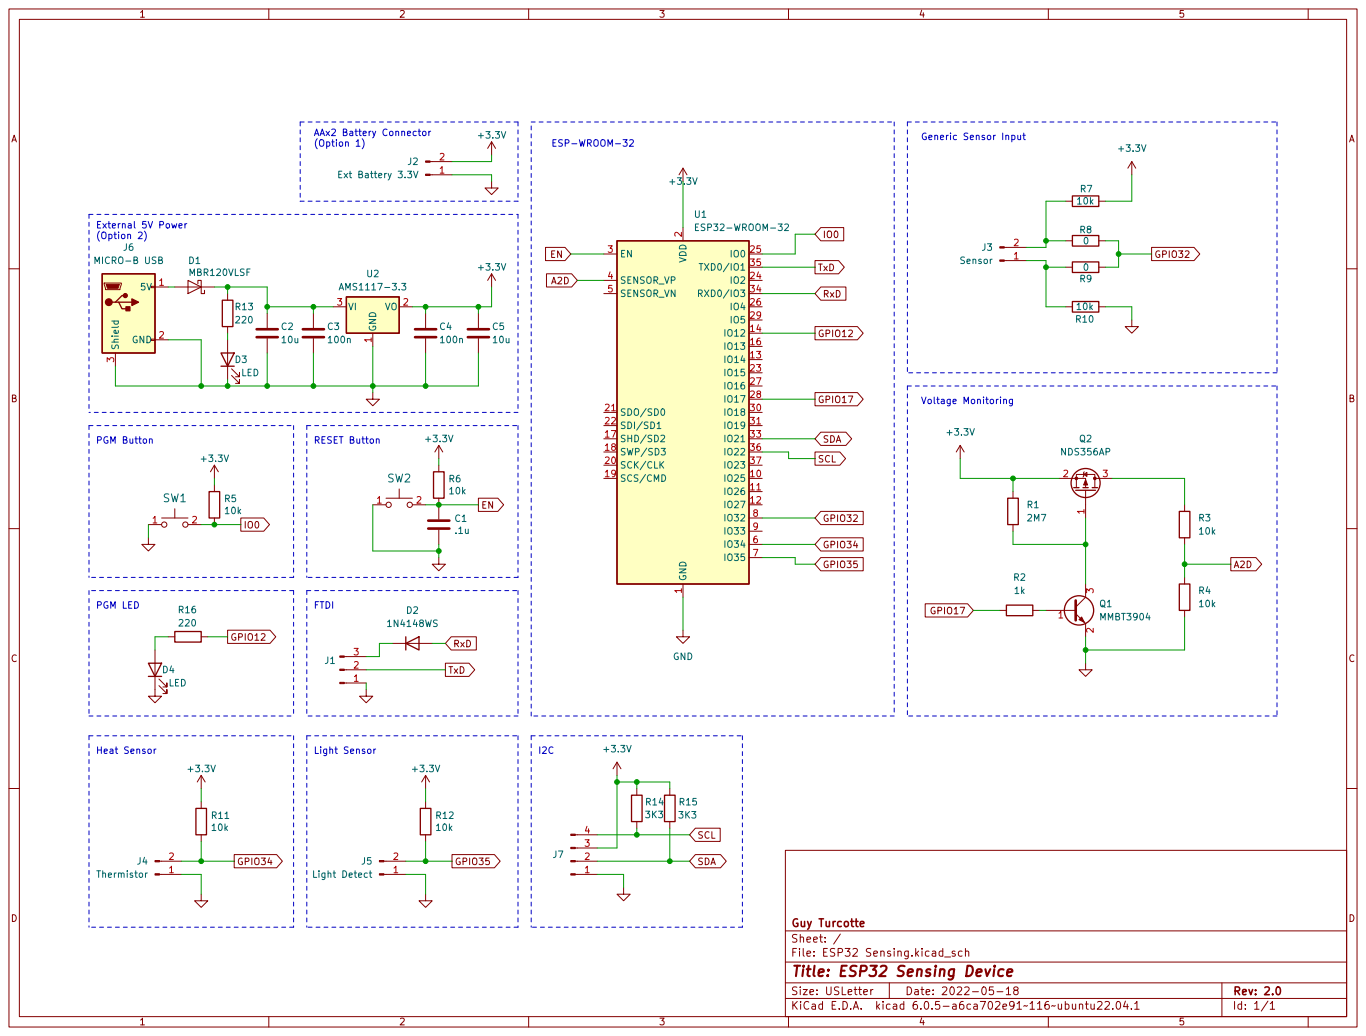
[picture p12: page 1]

2 SCK/CLK 20 SDO/SD0 21 SDI/SD1 22

File: ESP32 Sensing.kicad_sch Sheet: / Guy Turcotte GND

Id: 1/1 Title: ESP32 Sensing Device

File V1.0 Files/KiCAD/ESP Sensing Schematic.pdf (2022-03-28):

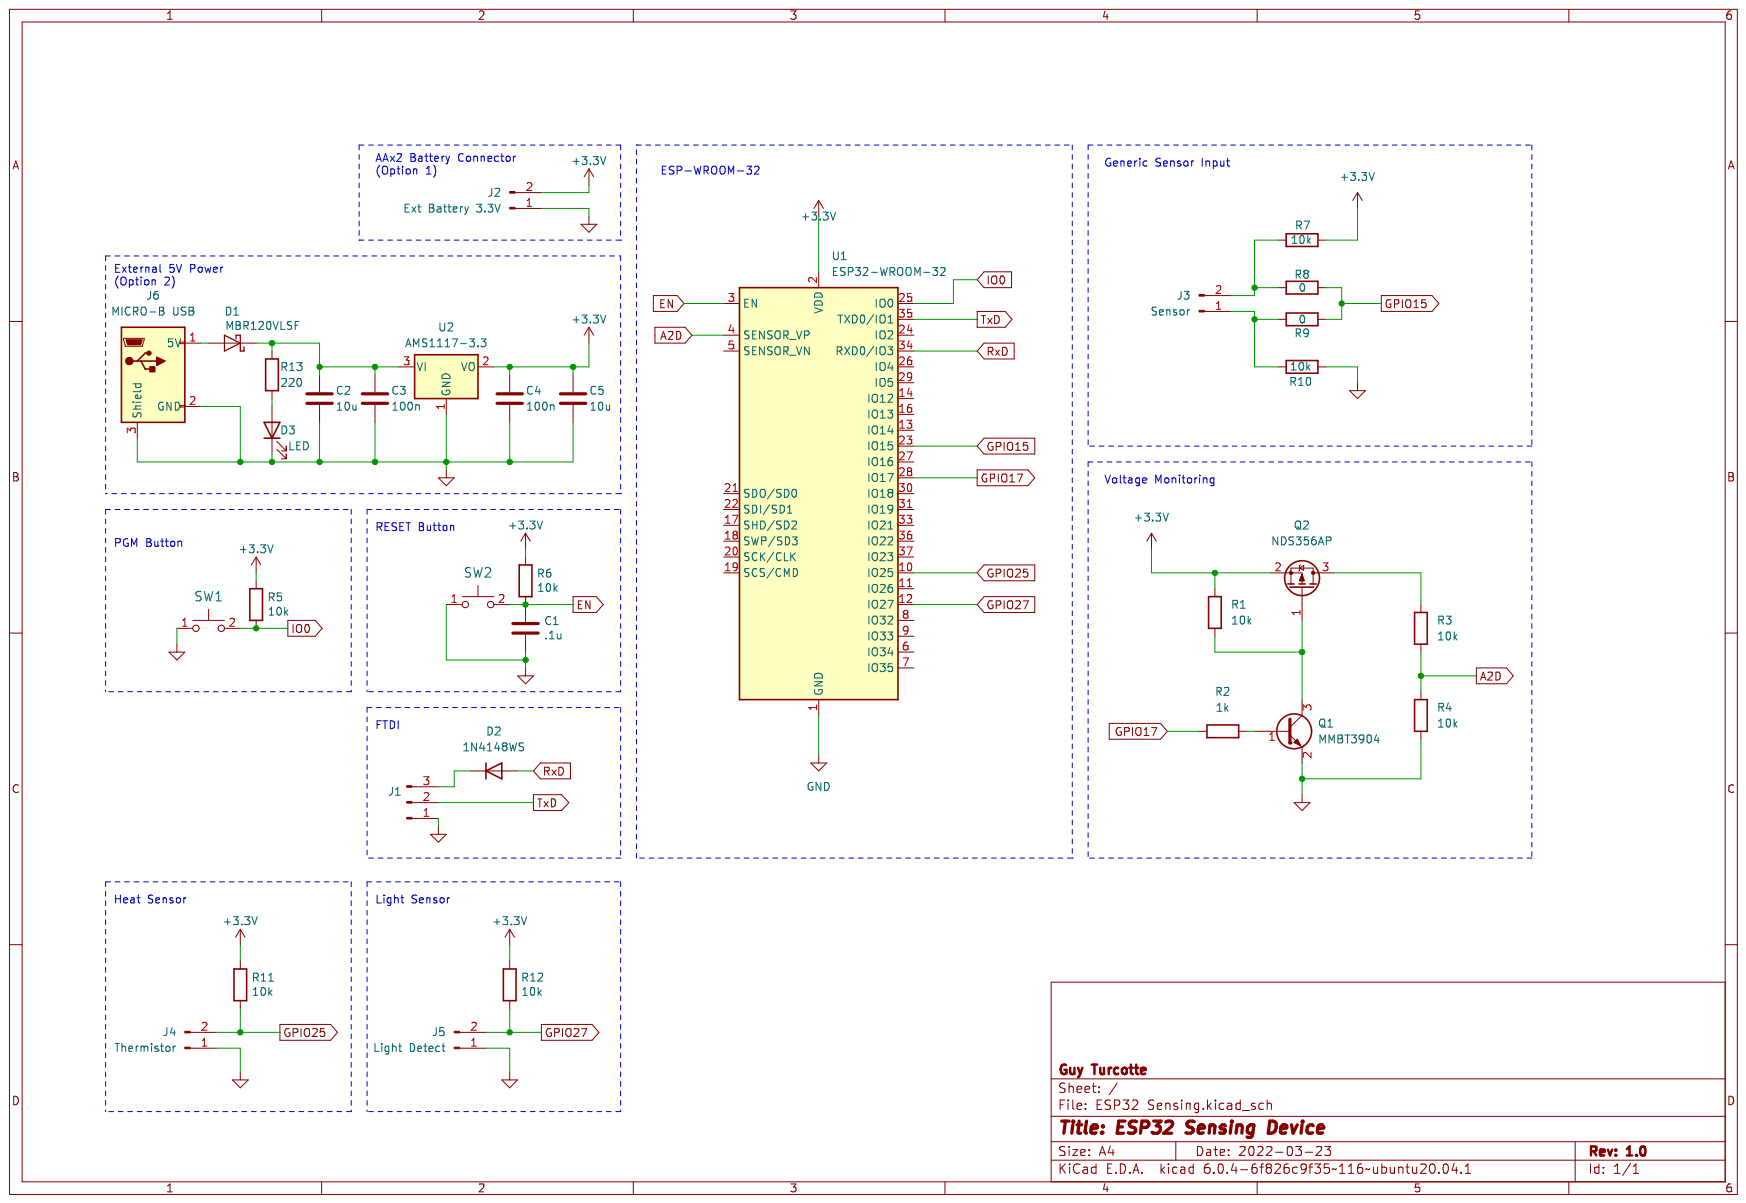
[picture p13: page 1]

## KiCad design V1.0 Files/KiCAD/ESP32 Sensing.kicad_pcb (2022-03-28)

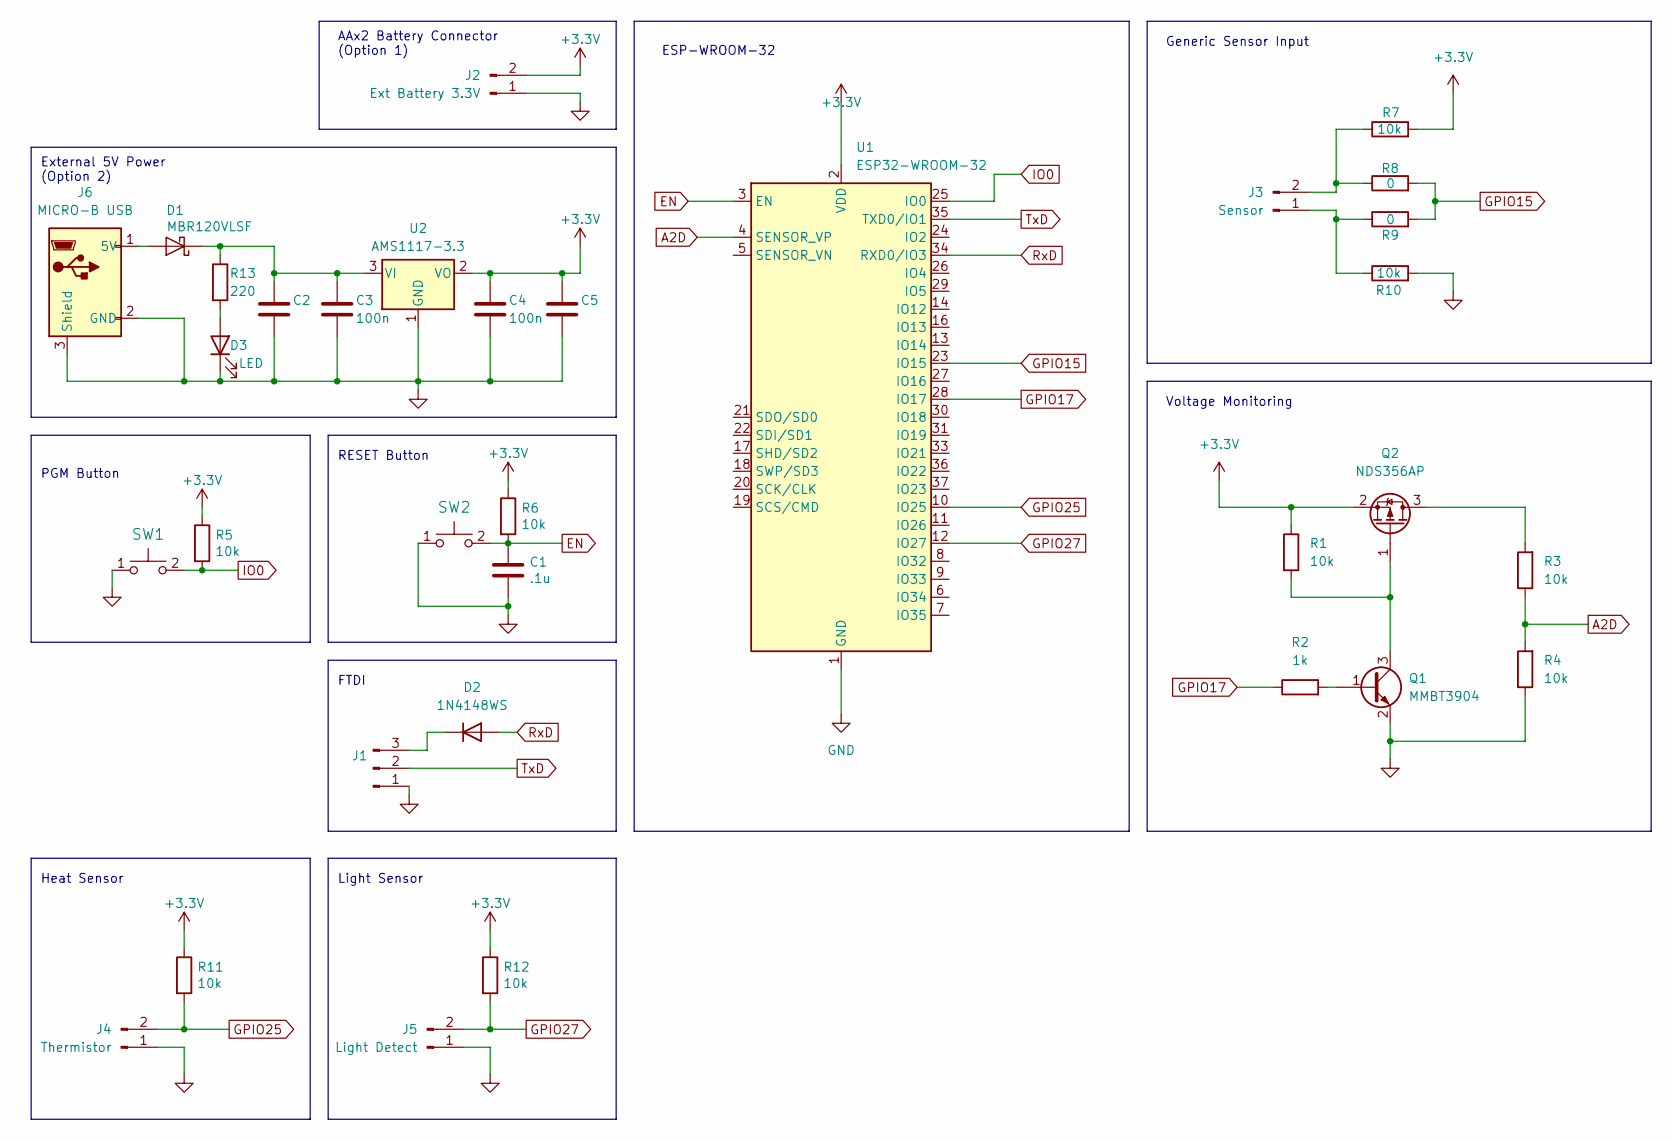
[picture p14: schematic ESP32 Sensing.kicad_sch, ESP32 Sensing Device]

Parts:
C1: .1u; C_0805_2012Metric_Pad1.18x1.45mm_HandSolder
C2: (no value)
C3, C4: 100n; C_0805_2012Metric_Pad1.18x1.45mm_HandSolder
C5: C_0805_2012Metric_Pad1.18x1.45mm_HandSolder
D1: MBR120VLSF; D_SOD-123F
D2: 1N4148WS; D_SOD-323
D3: LED; LED_0805_2012Metric_Pad1.15x1.40mm_HandSolder
J1: PinHeader_1x03_P2.54mm_Vertical
J2: Ext Battery 3.3V; PinHeader_1x02_P2.54mm_Vertical
J3: Sensor; PinHeader_1x02_P2.54mm_Vertical
J4: Thermistor; PinHeader_1x02_P2.54mm_Vertical
J5: Light Detect; PinHeader_1x02_P2.54mm_Vertical
J6: MICRO-B USB; MICRO-B_USB_POWER
Q1: MMBT3904; SOT-23
Q2: NDS356AP; SOT-23
R1, R3, R4, R5, R6, R7, R10, R11, R12: 10k; R_0805_2012Metric_Pad1.20x1.40mm_HandSolder
R2: 1k; R_0805_2012Metric_Pad1.20x1.40mm_HandSolder
R8, R9: 0; R_0805_2012Metric_Pad1.20x1.40mm_HandSolder
R13: 220; R_0805_2012Metric_Pad1.20x1.40mm_HandSolder
SW1: PTS526_SK15_SMTR2_LFS
SW2: PTS526_SK15_SMTR2_LFS
U1: ESP32-WROOM-32
U2: AMS1117-3.3; SOT-223-3_TabPin2

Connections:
+3V3: C4.1, C5.1, J2.2, Q2.2 (S), R1.1, R5.1, R6.1, R7.2, R11.1, R12.1, U1.2 (VDD), U2.2 (VO)
A2D: R3.1, R4.2, U1.4 (SENSOR_VP)
EN: C1.1, R6.2, SW2.2, U1.3 (EN)
GPIO15: R8.2, R9.2, U1.23 (IO15)
GPIO17: R2.1, U1.28 (IO17)
GPIO25: J4.2, R11.2, U1.10 (IO25)
GPIO27: J5.2, R12.2, U1.12 (IO27)
IO0: R5.2, SW1.2, U1.25 (IO0)
unnamed: C2.1, C3.1, D1.1 (K), R13.1, U2.3 (VI)
unnamed: D1.2 (A), J6.1 (5V)
unnamed: D2.1 (K), J1.3
unnamed: D3.2 (A), R13.2
unnamed: J3.1, R9.1, R10.1
unnamed: J3.2, R7.1, R8.1
unnamed: Q1.1 (B), R2.2
unnamed: Q1.3 (C), Q2.1 (G), R1.2
unnamed: Q2.3 (D), R3.2
RxD: D2.2 (A), U1.34 (RXD0/IO3)
TxD: J1.2, U1.35 (TXD0/IO1)

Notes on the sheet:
Heat Sensor
Voltage Monitoring
ESP-WROOM-32
Generic Sensor Input
RESET Button
AAx2 Battery Connector (Option 1)
FTDI
PGM Button
Light Sensor
External 5V Power (Option 2)

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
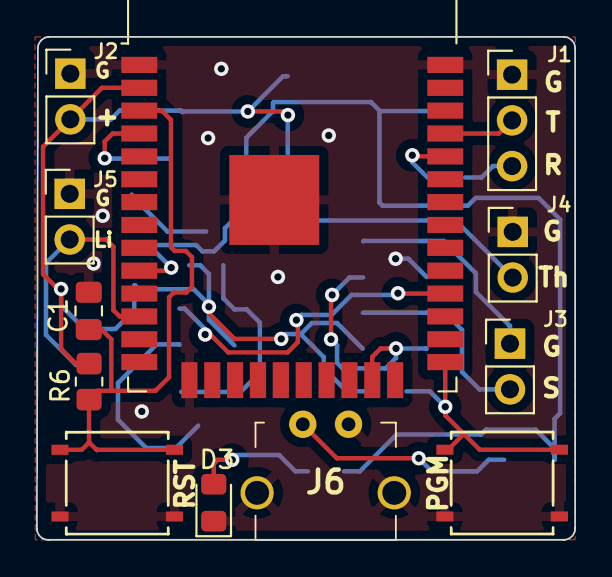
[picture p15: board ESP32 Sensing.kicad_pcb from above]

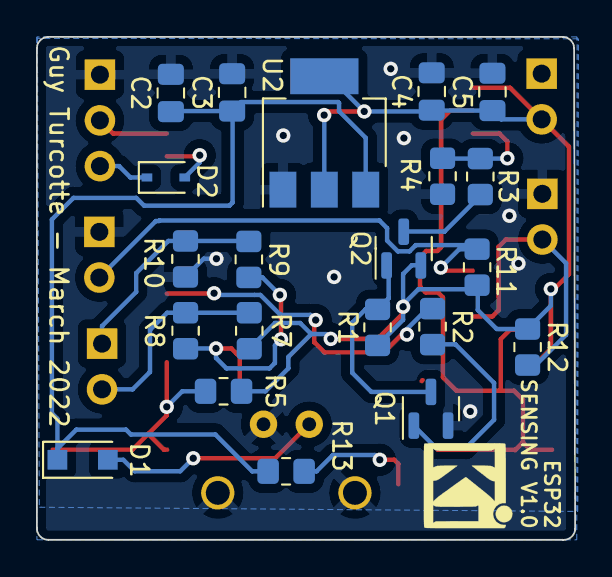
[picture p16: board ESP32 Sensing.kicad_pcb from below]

Board: 2 copper layers, 29.9 x 27.9 mm, 33 parts (21 on the bottom side), 20 nets.

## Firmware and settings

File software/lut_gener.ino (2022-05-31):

#include <Arduino.h>
#include <driver/dac.h>

// Based on original work from Helmut Weber (https://github.com/MacLeod-D/ESP32-ADC)
// that he described at https://esp32.com/viewtopic.php?f=19&t=2881&start=30#p47663
// Modified with bug-fixed by Henry Cheung
//
// Build a ESP32 ADC Lookup table to correct ESP32 ADC linearity issue
// Run this sketch to build your own LUT for each of your ESP32, copy and paste the
// generated LUT to your sketch for using it, see example sketch on how to use it
//
// Version 2.0 - switch to use analogRead() instead of esp-idf function adcStart()
// Version 1.0 - original adoptation and bug fix based on Helmut Weber code

// #define GRAPH           // uncomment this for print on Serial Plotter
#define FLOAT_LUT          // uncomment this if you need float LUT

#define ADC_PIN 34         // GPIO 34 , uses any valid Ax pin as you wish
#define DAC DAC_CHANNEL_1  // GPIO 25 (DAC_CHANNEL_1) or 26 (DAC_CHANNEL_2)

float Results[4097];
float Res2[4096*5];

void dumpResults() {
  for (int i = 0; i < 4096; i++) {
    if (i % 16 == 0) {
      Serial.println();
      Serial.print(i); Serial.print(" - ");
    }
    Serial.print(Results[i], 2); Serial.print(", ");
  }
  Serial.println();
}

void dumpRes2() {
  Serial.println(F("Dump Res2 data..."));
  for (int i = 0; i < (5 * 4096); i++) {
      if (i % 16 == 0) {
        Serial.println(); Serial.print(i); Serial.print(" - ");
      }
      Serial.print(Res2[i],3); Serial.print(", ");
    }
    Serial.println();
}

void setup() {
    dac_output_enable(DAC);    // pin 25 or 26
    dac_output_voltage(DAC, 0);
    analogReadResolution(12);
    Serial.begin(115200);
    delay(1000);
}

void loop() {

    Serial.print(F("Test Linearity "));
    for (int j=0; j<500; j++) {
      if (j % 100 == 0) Serial.print(".");
      for (int i=0;i<256;i++) {
          dac_output_voltage(DAC, (i & 0xff));
          delayMicroseconds(100);
          Results[i*16]=0.9*Results[i*16] + 0.1*analogRead(ADC_PIN);
      }
    }
    Serial.println();
    // dumpResults();

    Serial.println(F("Calculate interpolated values .."));
    Results[4096] = 4095.0;
    for (int i=0; i<256; i++) {
       for (int j=1; j<16; j++) {
          Results[i*16+j] = Results[i*16] + (Results[(i+1)*16] - Results[(i)*16])*(float)j / (float)16.0;
       }
    }
    // dumpResults();

    Serial.println(F("Generating LUT .."));
    for (int i=0; i<4096; i++) {
        Results[i]=0.5 + Results[i];
    }
    // dumpResults();

    Results[4096]=4095.5000;
    for (int i=0; i<4096; i++) {
       for (int j=0; j<5; j++) {
          Res2[i*5+j] = Results[i] + (Results[(i+1)] - Results[i]) * (float)j / (float)10.0;
       }
    }
    // dumpRes2();

    for (int i=1; i<4096; i++) {
        int index;
        float minDiff=99999.0;
        for (int j=0; j<(5*4096); j++) {
            float diff=fabs((float)(i) - Res2[j]);
            if(diff<minDiff) {
                minDiff=diff;
                index=j;
            }
        }
        Results[i]=(float)index;
    }
    // dumpResults();

    for (int i=0; i<(4096); i++) {
        Results[i]/=5;
    }

#ifdef GRAPH

    while(1) {
      for (int i=2; i<256; i++) {
        dac_output_voltage(DAC, (i & 0xff));
        delayMicroseconds(100);
        float r = Results[analogRead(ADC_PIN)];
        Serial.print(i*16); Serial.print(" "); Serial.println(r);
      }
    }

#else

    Serial.println();

#ifdef FLOAT_LUT
    Serial.println("const float ADC_LUT[4096] = { 0,");
    for (int i=1; i<4095; i++) {
       Serial.print(Results[i],4); Serial.print(",");
       if ((i%15)==0) Serial.println();
    }
    Serial.println(Results[4095]);
    Serial.println("};");
#else
    Serial.println("const int ADC_LUT[4096] = { 0,");
    for (int i=1; i<4095; i++) {
      Serial.print((int)Results[i]); Serial.print(",");
      if ((i%15)==0) Serial.println();
    }
    Serial.println((int)Results[4095]);
    Serial.println("};");
#endif
    while(1);
#endif

}

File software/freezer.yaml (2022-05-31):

# FREEZER
#
# I/O Configuration:
# -----------------
#
# Thermistor:
#   Analog readout: GPIO 34
#   Read Enable: GPIO 25
#
# Freezer Door: GPIO 32
#
# Debug LED: GPIO 12
#
# Values transmitted to Home Assistant:
# ------------------------------------
#
#  - Freezer Temp
#  - Freezer Door Open
#  - Freezer ADC Th
#  - Freezer Resistance Th
#  - Freezer WiFi Strength
#
# The ADC, Resistance and Temp values are read every 15 minutes.
# The WiFi Strength value is read every 24 hours.

substitutions:
  devicename: freezer
  
esphome:
  name: $devicename
  includes:
    - .freezer_adc_lut.h # Generated with lut_gener.ino

esp32:
  board: esp32dev
  framework:
    type: arduino

# Enable logging
#logger:

# Enable Home Assistant API
api:

ota:
  password: "blablabla"

wifi:
  ssid: !secret wifi_ssid
  password: !secret wifi_password
  fast_connect: true

  # Enable fallback hotspot (captive portal) in case wifi connection fails
  ap:
    ssid: "Freezer Fallback Hotspot"
    password: "blablabla"

captive_portal:

output:
  - platform: gpio
    pin: 25
    id: thermistor_enable
    inverted: false
  - platform: gpio
    pin: 12
    id: led
    inverted: false

binary_sensor:
  - platform: gpio
    pin: 
      number: GPIO32
      inverted: false
      mode:
        input: True
    filters:
      - delayed_off: 25ms
      - delayed_on: 25ms
    name: "Freezer Door Open"
    on_press:
      then:
        - output.turn_on: led
    on_release:
        - output.turn_off: led

sensor:    
  - platform: wifi_signal
    name: "Freezer WiFi Strength"
    update_interval: 24h

  - platform: adc
    id: adc_thermistor
    pin: 34
    raw: true
    attenuation: 11db
    update_interval: never
    unit_of_measurement: V
    name: "Freezer ADC Th"
    filters:
      - lambda: return ADC_LUT[(int)x] * 3.3 / 4095.0;

  - platform: resistance
    id: resistance_thermistor
    sensor: adc_thermistor
    configuration: DOWNSTREAM
    resistor: 10.0kOhm
    name: "Freezer Resistance Th"

  - platform: ntc
    sensor: resistance_thermistor
    calibration:
      b_constant: 3950
      reference_temperature: 25°C
      reference_resistance: 10kOhm
    unit_of_measurement: "°C"
    accuracy_decimals: 2
    icon: mdi:thermometer
    name: "Freezer Temp"

interval:
  - interval: 15min
    then:
      - output.turn_on: thermistor_enable
      - component.update: adc_thermistor
      - output.turn_off: thermistor_enable

mqtt: !include .mqtt.yaml

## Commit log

2022-03-23 Folders Re-org
    [ESP32 Sensing.csv, ESP32 Sensing.kicad_pcb, ESP32 Sensing.kicad_sch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]
2022-03-23 Add Gerber
    [ESP32 Sensing-B_Cu.gbl, ESP32 Sensing-B_Mask.gbs, ESP32 Sensing-B_Paste.gbp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]
2022-03-23 Documentation update
    [ESP32 Sensing.kicad_sch]
2022-03-24 Some symbol adjustments
    [ESP32 Sensing.csv, ESP32 Sensing.kicad_pcb, ESP32 Sensing.kicad_sch]
2022-03-28 Doc update
    [ESP32 Sensing.kicad_pcb, Test2.stp]
2022-03-28 Modified linear regulator capacitor values
    [ESP32 Sensing.csv, ESP32 Sensing.kicad_pcb, ESP32 Sensing.kicad_sch]
2022-05-18 README Update. Added Battery level test.
2022-05-19 Version 2.0
    [ESP32 Sensing-B_Cu.gbl, ESP32 Sensing-B_Mask.gbs, ESP32 Sensing-B_Paste.gbp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]
2022-05-19 Updated Gerber files
    [ESP32 Sensing-B_Cu.gbl, ESP32 Sensing-B_Mask.gbs, ESP32 Sensing-B_Paste.gbp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]
